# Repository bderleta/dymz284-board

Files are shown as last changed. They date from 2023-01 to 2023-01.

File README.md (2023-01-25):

# dymz284-board
Dual YMZ284 synth board design using retro technology (THT elements, DIP packages). Board designed to fit Hammond 1455C802 enclosure.

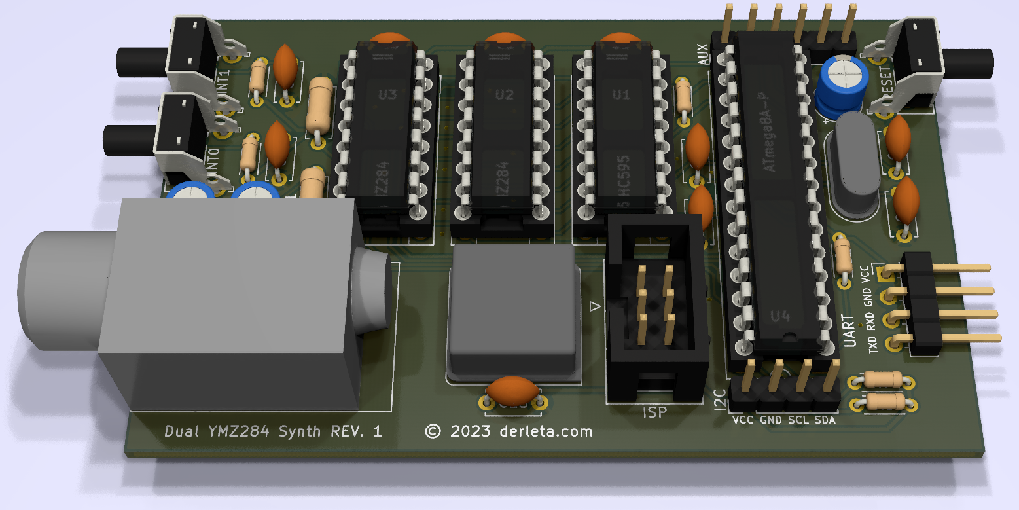
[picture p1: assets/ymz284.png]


An application of ATMega8 8-bit MCU in PDIP package capable of driving two of YMZ284 PSG chips. This is a simplified derivative of [DYM2149](https://github.com/bderleta/dym2149-board) and runs similar firmware, but there are some differences:

- PSG data inputs are driven from '595 shift register controlled via SPI, instead of `PORTA` (note: '595 used has to be capable of running at 8 MHz+, as firmware uses SPI2X, making SPI clock equal to Tosc/2; plain SN74HC595 won't make it)
- Control pin assignments and names are different
- There is no JTAG and no SPI RAM
- Instead of single INT2 button, there are two hardware-debounced interrupt triggering buttons (INT0 and INT1)

As YMZ284 has only single DAC output, there is no mixing stage present, first PSG is assigned to the left channel, second - to the right. In contrary to YM2149 chips, YMZ has clock divider permamently enabled, therefore it is necessary to provide generator twice as fast to achieve identical behavior. This device has been tested with 4 MHz and 3.579545 MHz CXOs.

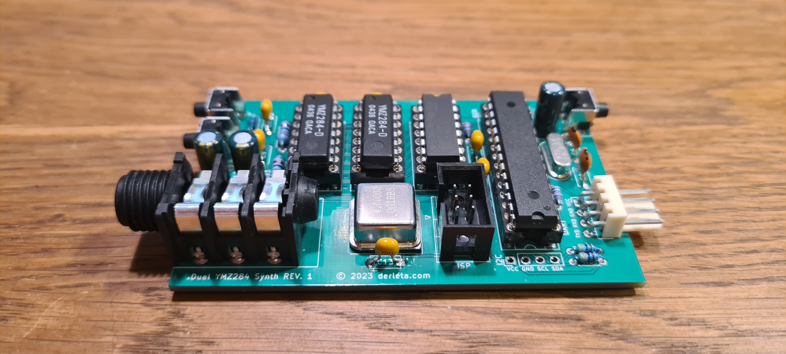
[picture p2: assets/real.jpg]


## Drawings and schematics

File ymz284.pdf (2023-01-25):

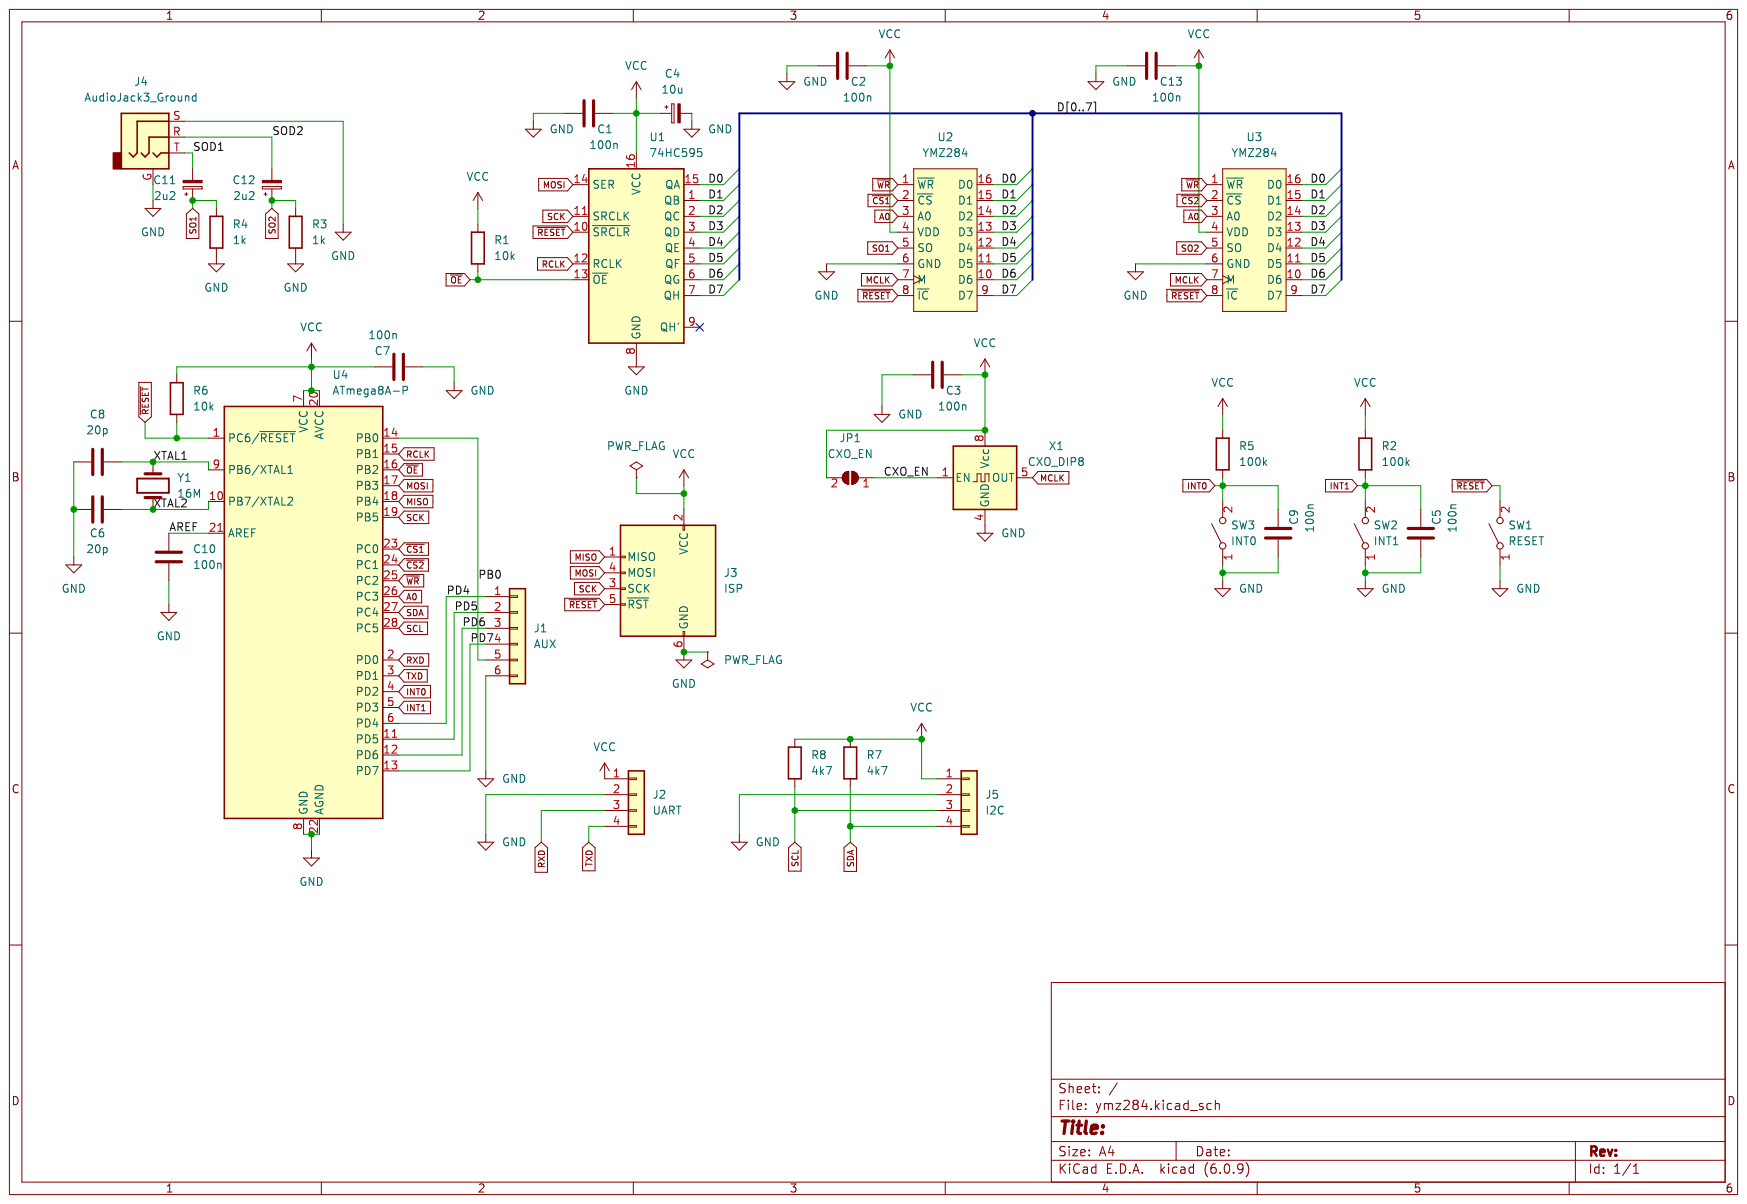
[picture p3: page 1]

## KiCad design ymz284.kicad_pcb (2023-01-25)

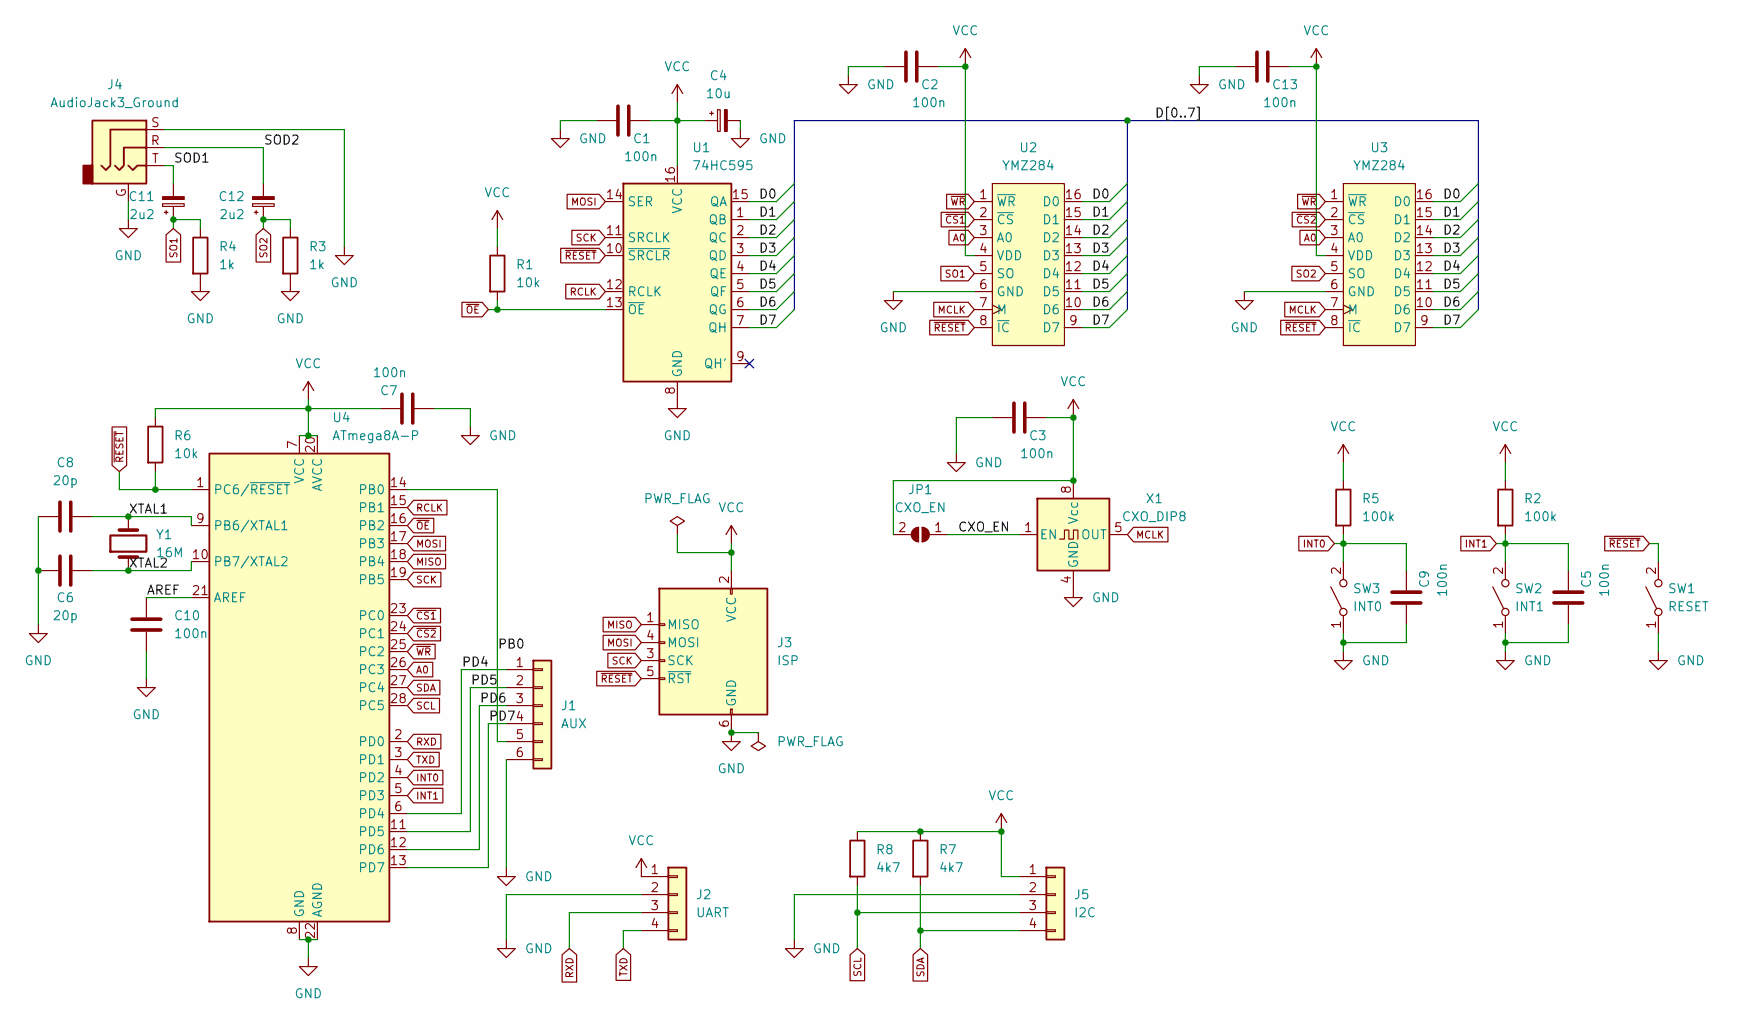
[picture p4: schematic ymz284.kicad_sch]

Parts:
C1, C2, C3, C5, C7, C9, C10, C13: 100n; C_Disc_D5.0mm_W2.5mm_P5.00mm
C4: 10u; CP_Radial_D5.0mm_P2.50mm
C6, C8: 20p; C_Disc_D5.0mm_W2.5mm_P5.00mm
C11, C12: 2u2; CP_Radial_D5.0mm_P2.50mm
J1: AUX; PinHeader_1x06_P2.54mm_Vertical
J2: UART; PinHeader_1x04_P2.54mm_Horizontal
J3: ISP; IDC-Header_2x03_P2.54mm_Vertical
J4: AudioJack3_Ground; Jack_6.35mm_Neutrik_NRJ3HF-1_Horizontal
J5: I2C; PinHeader_1x04_P2.54mm_Vertical
JP1: CXO_EN; SolderJumper-2_P1.3mm_Open_RoundedPad1.0x1.5mm
R1, R6: 10k; R_Axial_DIN0204_L3.6mm_D1.6mm_P5.08mm_Horizontal
R2, R5: 100k; R_Axial_DIN0204_L3.6mm_D1.6mm_P5.08mm_Horizontal
R3, R4: 1k; R_Axial_DIN0207_L6.3mm_D2.5mm_P7.62mm_Horizontal
R7, R8: 4k7; R_Axial_DIN0204_L3.6mm_D1.6mm_P5.08mm_Horizontal
SW1: RESET; SW_Tactile_SPST_Angled_PTS645Vx83-2LFS
SW2: INT1; SW_Tactile_SPST_Angled_PTS645Vx83-2LFS
SW3: INT0; SW_Tactile_SPST_Angled_PTS645Vx83-2LFS
U1: 74HC595; DIP-16_W7.62mm_Socket
U2, U3: YMZ284; DIP-16_W7.62mm_Socket
U4: ATmega8A-P; DIP-28_W7.62mm_Socket
X1: CXO_DIP8; Oscillator_DIP-8
Y1: 16M; Crystal_HC49-4H_Vertical

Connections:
/AREF: C10.2, U4.21 (AREF)
/CXO_EN: JP1.1 (A), X1.1 (EN)
/D0: U1.15 (QA), U2.16 (D0), U3.16 (D0)
/D1: U1.1 (QB), U2.15 (D1), U3.15 (D1)
/D2: U1.2 (QC), U2.14 (D2), U3.14 (D2)
/D3: U1.3 (QD), U2.13 (D3), U3.13 (D3)
/D4: U1.4 (QE), U2.12 (D4), U3.12 (D4)
/D5: U1.5 (QF), U2.11 (D5), U3.11 (D5)
/D6: U1.6 (QG), U2.10 (D6), U3.10 (D6)
/D7: U1.7 (QH), U2.9 (D7), U3.9 (D7)
/PB0: J1.5, U4.14 (PB0)
/PD4: J1.1, U4.6 (PD4)
/PD5: J1.2, U4.11 (PD5)
/PD6: J1.3, U4.12 (PD6)
/PD7: J1.4, U4.13 (PD7)
/SOD1: C11.2, J4.T
/SOD2: C12.2, J4.R
/XTAL1: C8.1, U4.9 (PB6/XTAL1), Y1.2
/XTAL2: C6.2, U4.10 (PB7/XTAL2), Y1.1
A0: U2.3 (A0), U3.3 (A0), U4.26 (PC3)
GND: C1.1, C2.1, C3.1, C4.2, C5.1, C6.1, C7.1, C8.2, C9.1, C10.1, C13.1, J1.6, J2.2, J3.6 (GND), J4.G, J4.S, J5.2, R3.2, R4.2, SW1.1 (A), SW2.1 (A), SW3.1 (A), U1.8 (GND), U2.6 (GND), U3.6 (GND), U4.8 (GND), U4.22 (AGND), X1.4 (GND)
INT0: C9.2, R5.2, SW3.2 (B), U4.4 (PD2)
INT1: C5.2, R2.2, SW2.2 (B), U4.5 (PD3)
MCLK: U2.7 (M), U3.7 (M), X1.5 (OUT)
MISO: J3.1 (MISO), U4.18 (PB4)
MOSI: J3.4 (MOSI), U1.14 (SER), U4.17 (PB3)
RCLK: U1.12 (RCLK), U4.15 (PB1)
RXD: J2.3, U4.2 (PD0)
SCK: J3.3 (SCK), U1.11 (SRCLK), U4.19 (PB5)
SCL: J5.3, R8.2, U4.28 (PC5)
SDA: J5.4, R7.2, U4.27 (PC4)
SO1: C11.1, R4.1, U2.5 (SO)
SO2: C12.1, R3.1, U3.5 (SO)
TXD: J2.4, U4.3 (PD1)
VCC: C1.2, C2.2, C3.2, C4.1, C7.2, C13.2, J2.1, J3.2 (VCC), J5.1, JP1.2 (B), R1.1, R2.1, R5.1, R6.1, R7.1, R8.1, U1.16 (VCC), U2.4 (VDD), U3.4 (VDD), U4.7 (VCC), U4.20 (AVCC), X1.8 (Vcc)
~CS1: U2.2 (~CS), U4.23 (PC0)
~CS2: U3.2 (~CS), U4.24 (PC1)
~OE: R1.2, U1.13 (~OE), U4.16 (PB2)
~RESET: J3.5 (~RST), R6.2, SW1.2 (B), U1.10 (~SRCLR), U2.8 (~IC), U3.8 (~IC), U4.1 (PC6/~RESET)
~WR: U2.1 (~WR), U3.1 (~WR), U4.25 (PC2)

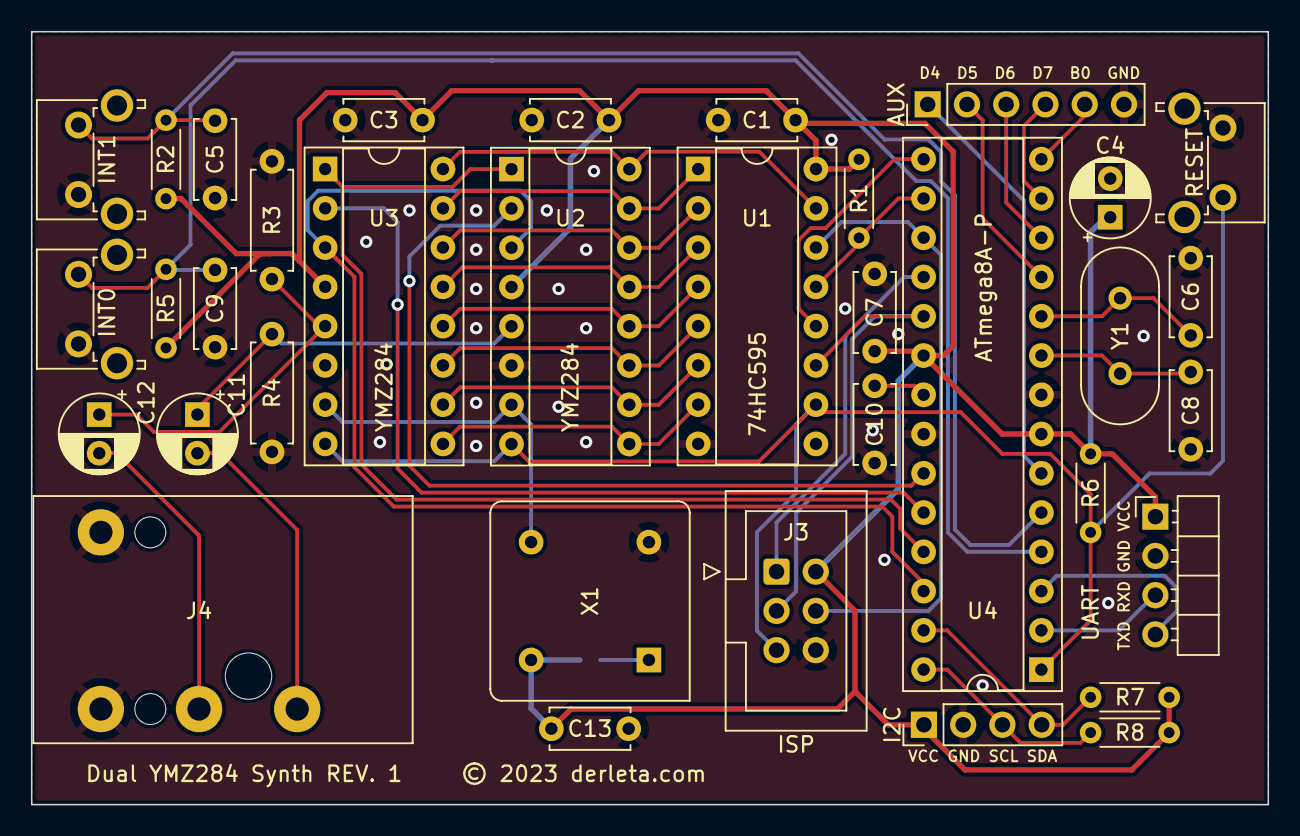
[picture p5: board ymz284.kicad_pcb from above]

Board: 2 copper layers, 80.0 x 50.0 mm, 36 parts (1 on the bottom side), 40 nets.

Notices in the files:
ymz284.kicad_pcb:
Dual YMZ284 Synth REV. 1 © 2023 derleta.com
